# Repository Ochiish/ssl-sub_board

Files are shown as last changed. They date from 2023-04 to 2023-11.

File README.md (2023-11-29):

# SubBoard for SSL
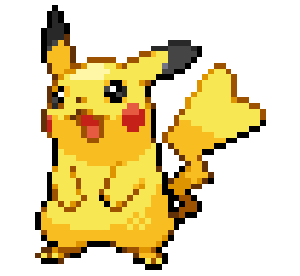
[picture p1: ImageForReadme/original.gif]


## Overview

This is a sub-board installed in the SSL robot.
The boost circuit, neopixel, phototransistor, etc. are controlled by stm32, and CAN communication is performed with the main board.

## Requirement

- KiCad 7.0.5

## Usage

Good luck...

## Features

This is a sub-board installed in an SSL robot. The board is equipped with various components such as a boost circuit, NeoPixels, phototransistors, etc., all controlled by an STM32 microcontroller. 

- This microcontroller offers advanced programming and processing capabilities, efficiently managing the robot's diverse functions.

- The boost circuit optimizes power supply, ensuring each component on the board operates at the correct voltage. It elevates the low voltage from the battery, distributing power as needed.

- NeoPixels are individually controllable LEDs used for visual feedback and status indication on the robot. These LEDs can be customized in color and brightness through programming, intuitively conveying the robot's status to the operator.

- Phototransistors detect light intensity and convert this information into digital signals. This is a crucial sensor for environmental awareness and obstacle detection in the robot.

- Furthermore, this robot is equipped with a thermistor for measuring the temperature of the solenoid coil. The thermistor plays a vital role in monitoring the heat generated by the solenoid, preventing overheating and enhancing the robot's safety and equipment lifespan.

- Additionally, the sub-board incorporates protective circuits around the power supply, safeguarding it against overvoltage and short circuits. 

- These circuits are essential for maintaining power stability while minimizing electrical risks.

- The sub-board communicates with the main board using the CAN communication protocol. CAN communication is known for its high reliability and error detection capabilities, ensuring secure data exchange between different parts of the robot. This allows for smooth overall operation and the ability to perform more complex tasks.

In this way, the sub-board supports crucial functions of the SSL robot, drawing out the robot's maximum performance through advanced technology and meticulous design.

<p align="center">
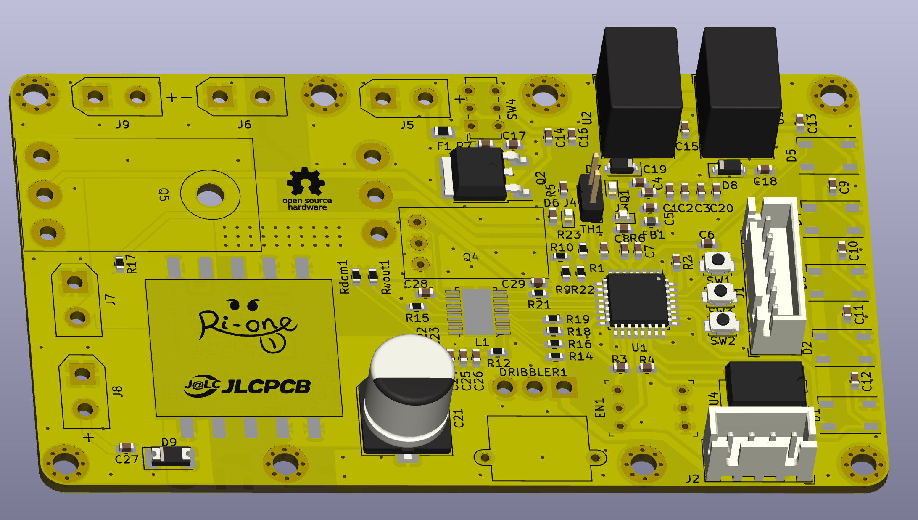
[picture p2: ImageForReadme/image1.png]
  

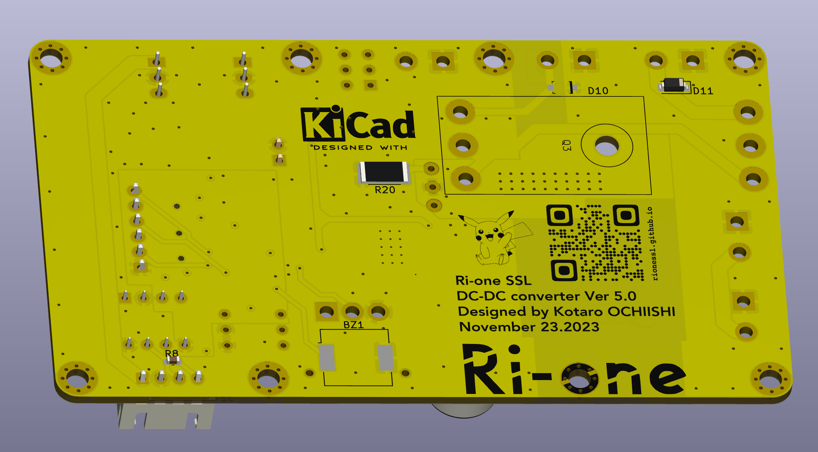
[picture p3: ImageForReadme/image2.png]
  
</p>

## Reference

https://www.analog.com/media/jp/technical-documentation/data-sheets/j3751fc.pdf

## Author

[@Allsatako](http://twitter.com/Allsatako)

mail to: rionesslq@gmail.com

## Licence

There is no license as this is open source hardware.

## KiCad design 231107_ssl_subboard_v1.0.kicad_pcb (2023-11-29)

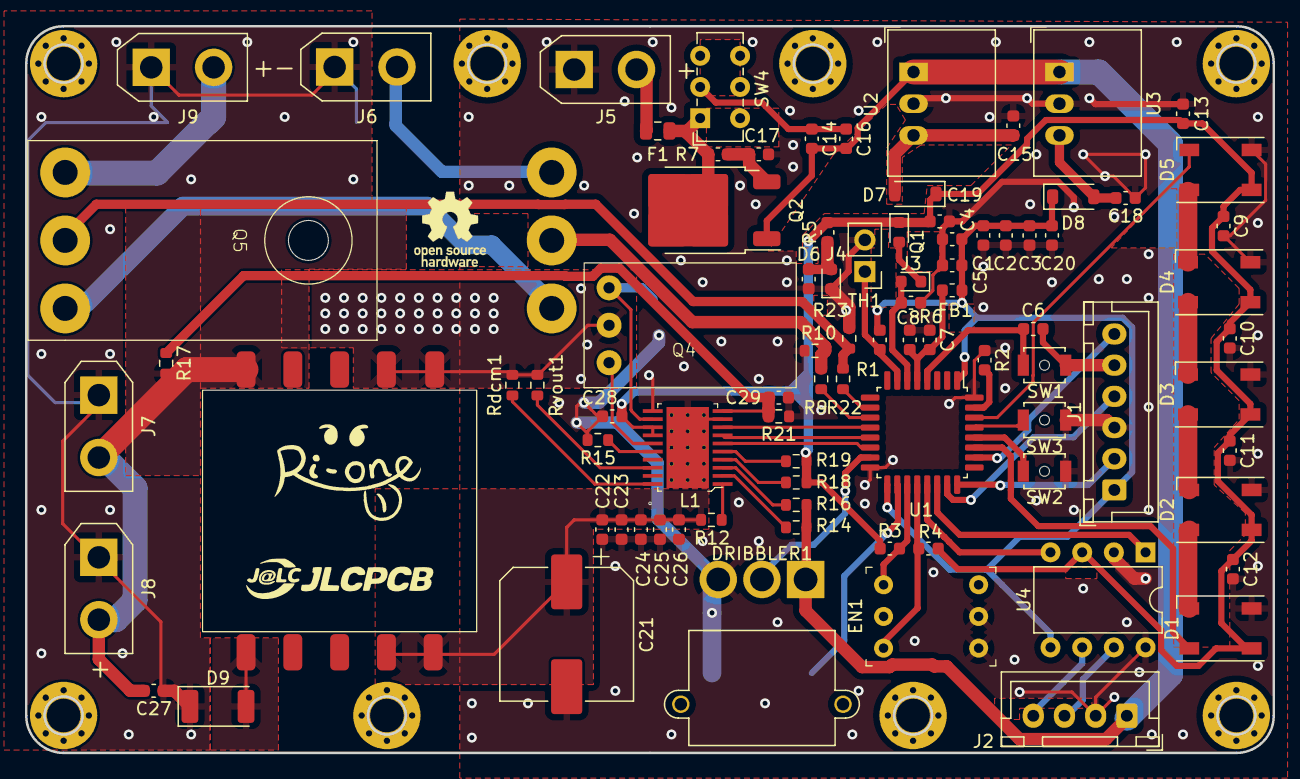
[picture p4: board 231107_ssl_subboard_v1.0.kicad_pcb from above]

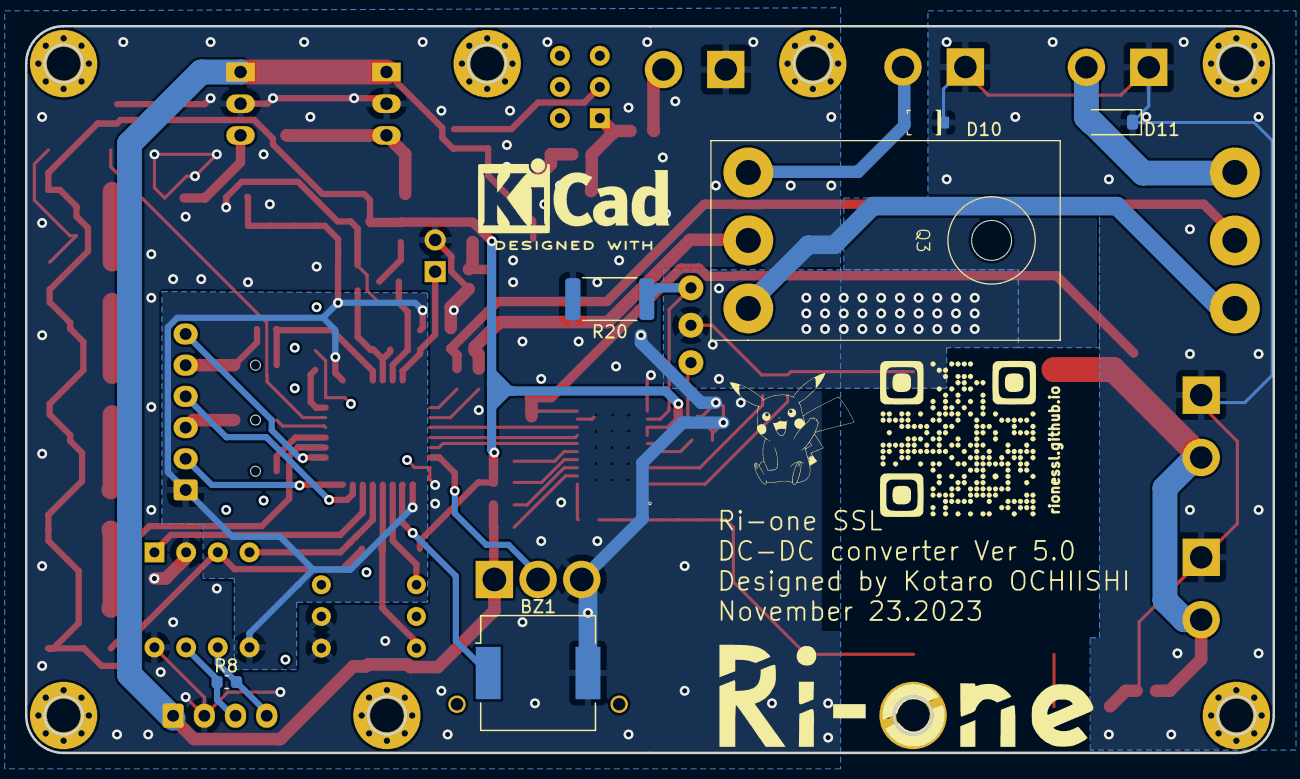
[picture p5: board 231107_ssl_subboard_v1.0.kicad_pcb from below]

Board: 2 copper layers, 100.0 x 58.2 mm, 93 parts (6 on the bottom side), 62 nets.

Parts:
BZ1: Buzzer; Buzzer_CUI_CPT-9019S-SMT
C1, C2, C3, C4, C5, C6, C7, C8, C9, C10, C11, C12, C13, C14, C16, C17, C19, C20: 0.1uF; C_0603_1608Metric
C15, C18, C22, C23, C24, C25, C26: 2.2u; C_0603_1608Metric
C21: 680u; CP_Elec_10x10.5
C27: 0.47u; C_0603_1608Metric
C28, C29: 10n; C_0603_1608Metric
D1, D2, D3, D4, D5: ws2812b; LED_Cree-PLCC4_5x5mm_CW
D6: LED; C_0603_1608Metric
D7, D8: SS2040FL; D_SOD-123
D9: 1.5KExxA; D_2010_5025Metric
D10: 1.5KExxA; SOD-123
D11: 1.5KExxA; D_SOD-123
DRIBBLER1: MR30PW-M; AMASS_MR30PW-M_1x03_P3.50mm_Horizontal
EN1: RotaryEncoder_Switch; SOCKET_DIP-6_7.62mm_Conn
F1: Fuse; Fuse_0805_2012Metric
FB1: FerriteBead_Small; L_0603_1608Metric
J1: pc to stm32; JST_XH_B6B-XH-A_1x06_P2.50mm_Vertical
J2: main to sub; JST_XH_B4B-XH-A_1x04_P2.50mm_Vertical
J3: PHOTOCOUPLER; LED_0603_1608Metric
J4: LED; LED_0603_1608Metric
J5: lipo_3cell; AMASS_XT30UPB-M_1x02_P5.0mm_Vertical
J6: s1; AMASS_XT30UPB-F_1x02_P5.0mm_Vertical
J7: c1; AMASS_XT30UPB-F_1x02_P5.0mm_Vertical
J8: c2; AMASS_XT30UPB-F_1x02_P5.0mm_Vertical
J9: s2; AMASS_XT30UPB-F_1x02_P5.0mm_Vertical
L1: TSSOP-20-1EP_W4.4mm
Q1: Q_Photo_NPN; LED_0603_1608Metric
Q2: PMOS; TO-252-2
Q3, Q5: NMOS; IRFP150NPbF
Q4: Q_NMOS_DGS; tk20a60u
R1, R3, R4: 5k; C_0603_1608Metric
R2, R7: 10k; C_0603_1608Metric
R5: 470; C_0603_1608Metric
R6: 20k; C_0603_1608Metric
R8: 120; C_0603_1608Metric
R9, R22: 100; R_0603_1608Metric
R10, R23: 1k; R_0603_1608Metric
R12: 40.2k; R_0603_1608Metric
R14, R18: 69.8k; R_0603_1608Metric
R15: 1.65; R_0603_1608Metric
R16, R19: 475k; R_0603_1608Metric
R17: 124; R_0603_1608Metric
R20: 6m; R_2512_6332Metric
R21: 0.768k; R_0603_1608Metric
Rdcm1: 18.2k; R_0603_1608Metric
Rvout1: 40.2k; R_0603_1608Metric
SW1, SW2, SW3: SW_Push; SW_SPST_B3U-1000P-B
SW4: SW_SPST; SW_E-Switch_EG1271_SPDT
TH1: Thermistor; PinHeader_1x02_P2.54mm_Vertical
U1: STM32F303K8Tx; LQFP-32_7x7mm_P0.8mm
U2: M78AR05-1; Converter_DCDC_RECOM_R-78E-0.5_THT
U3: M78AR033-1; Converter_DCDC_RECOM_R-78E-0.5_THT
U4: MCP2562-E-P; DIP-8_W7.62mm
U5: 32052

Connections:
+3V3: C1.2, C2.2, C3.2, C4.2, C5.2, C20.2, D8.1 (K), FB1.1, J1.1, R1.2, U1.1 (VDD), U1.17 (VDD), U4.5 (Vio)
+5V: C9.1, C10.1, C11.1, C12.1, C13.1, C19.2, C28.1, D1.3 (VDD), D2.3 (VDD), D3.3 (VDD), D4.3 (VDD), D5.3 (VDD), D7.1 (K), L1.13 (VCC), L1.14 (LVGATE), Q1.1 (C), R3.1, R4.1, R5.2, R18.1, R19.1, U4.3 (VDD)
+15V: C14.2, C16.2, DRIBBLER1.1, J2.1, Q2.1 (D), R14.1, R16.1, U2.1 (IN), U3.1 (IN)
+BATT: F1.1, J5.2
CANH: J2.3, R8.2, U4.7 (CANH)
CANL: J2.4, R8.1, U4.6 (CANL)
CANRX: U1.21 (PA11), U4.4 (RXD)
CANTX: U1.22 (PA12), U4.1 (TXD)
CHARGE: L1.8 (CHARGE), U1.12 (PA6)
Cvtrans: C21.1, C22.1, C23.1, C24.1, C25.1, C26.1, R12.1, U5.4 (4IN), U5.5 (5IN)
DCDC_OUT: C27.1, D9.1 (A1), D10.1 (A1), D11.1 (A1), J6.1, J7.1, J8.1, J9.1
DIN: D1.4 (DIN), U1.27 (PB4)
DONE: L1.7 (DONE), U1.13 (PA7)
DOUT: D5.1 (DOUT), U1.30 (PB7)
DR_PWM: DRIBBLER1.2, U1.15 (PB1)
DR_SW: SW3.2, U1.29 (PB6)
Drain: Q4.1 (D), Rdcm1.2, Rvout1.2, U5.6 (6IN), U5.7 (7IN)
ENCODER_A: EN1.1 (A), R3.2, U1.19 (PA9)
ENCODER_B: EN1.3 (B), R4.2, U1.20 (PA10)
FAULT: L1.6 (FAULT), U1.14 (PB0)
GND: BZ1.2 (+), C1.1, C2.1, C3.1, C4.1, C5.1, C7.1, C8.1, C9.2, C10.2, C11.2, C12.2, C13.2, C15.1, C17.1, C18.1, C19.1, C20.1, C21.2, C22.2, C23.2, C24.2, C25.2, C26.2, C28.2, C29.2, D1.2 (GND), D2.2 (GND), D3.2 (GND), D4.2 (GND), D5.2 (GND), D6.1 (K), DRIBBLER1.3, EN1.4 (S1), EN1.5 (S2), J1.3, J2.2, J4.1, J5.1, L1.9 (CLAMP), L1.11 (CSN), L1.21 (GND), Q3.3 (S), Q5.3 (S), R2.1, R6.2, R10.1, R15.2, R20.2, R21.1, R23.1, SW2.1, SW3.1, TH1.2, U1.16 (VSS), U1.32 (VSS), U2.2 (GND), U3.2 (GND), U4.2 (VSS), U4.8 (STBY)
KICK_SW: SW2.2, U1.28 (PB5)
NRST: C6.1, J1.5, SW1.1
unnamed: BZ1.1 (-), U1.18 (PA8)
unnamed: D1.1 (DOUT), D2.4 (DIN)
unnamed: D2.1 (DOUT), D3.4 (DIN)
unnamed: D3.1 (DOUT), D4.4 (DIN)
unnamed: D4.1 (DOUT), D5.4 (DIN)
unnamed: D6.2 (A), J4.2, R5.1
unnamed: C15.2, D7.2 (A), U2.3 (OUT)
unnamed: C18.2, D8.2 (A), U3.3 (OUT)
unnamed: D10.2 (A2), J6.2, Q3.1 (D)
unnamed: D11.2 (A2), J9.2, Q5.1 (D)
unnamed: J3.1, Q1.2 (E)
unnamed: L1.12 (CSP), Q4.3 (S), R20.1
unnamed: C29.1, L1.10 (FB), R17.1, R21.2
unnamed: L1.15 (HVGATE), Q4.2 (G)
unnamed: L1.3 (OVLO1), R16.2
unnamed: L1.5 (OVLO2), R19.2
unnamed: L1.16 (RBG), R15.1
unnamed: L1.20 (RDCM), Rdcm1.1
unnamed: L1.18 (RVOUT), Rvout1.1
unnamed: L1.1 (RVTRANS), R12.2
unnamed: L1.2 (UVLO1), R14.2
unnamed: L1.4 (UVLO2), R18.2
unnamed: F1.2, Q2.2 (G), R7.2, SW4.1 (A)
unnamed: C17.2, Q2.3 (S), R7.1
unnamed: Q3.2 (G), R9.2, R10.2
unnamed: Q5.2 (G), R22.2, R23.2
unnamed: C14.1, C16.1, SW4.2 (B)
unnamed: R2.2, U1.31 (BOOT0)
unnamed: C6.2, SW1.2, U1.4 (NRST)
unnamed: R1.1, TH1.1, U1.7 (PA1)
unnamed: C7.2, C8.2, FB1.2, U1.5 (VDDA)
STRAIGHT: R9.1, U1.11 (PA5)
SYS-SWCLK: J1.2, U1.24 (PA14)
SYS-SWDIO: J1.4, U1.23 (PA13)
SYS-SWO: J1.6, U1.26 (PB3)
TR_SIG: J3.2, R6.1, U1.6 (PA0)
Vout: D9.2 (A2), U5.1 (1OUT)
tip: R22.1, U1.10 (PA4)
trans2: C27.2, J7.2, J8.2, R17.2, U5.10 (10OUT)

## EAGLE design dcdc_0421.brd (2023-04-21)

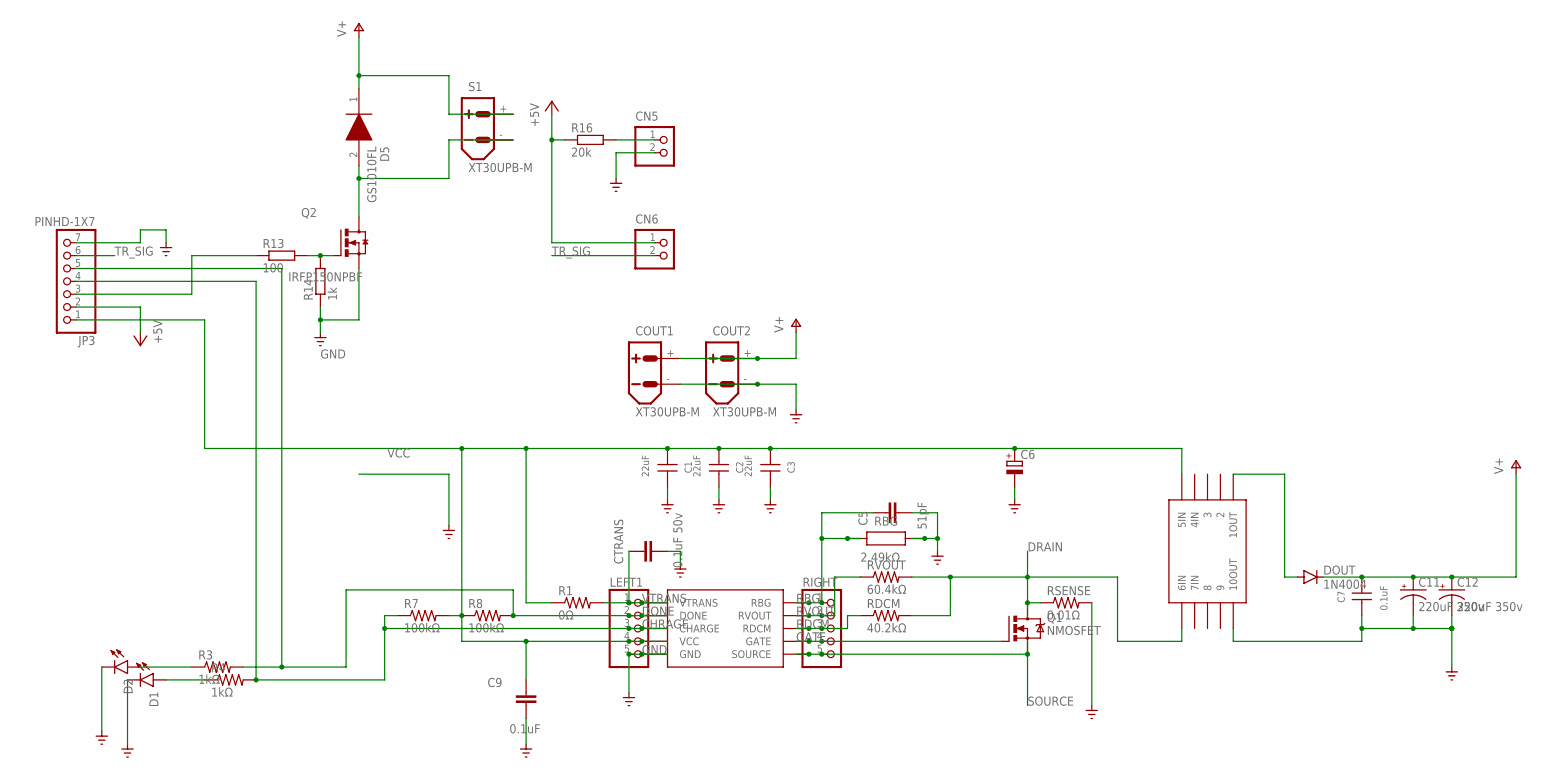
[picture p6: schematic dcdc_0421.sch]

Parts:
C1, C2, C3: 22uF; WCAP-CSGP_1210_H0.95
C5: 51pF; CAP_0603
C6: CPOL-EUTT2D6; TT2D6
C7: 0.1uF; WCAP-CSGP_1812_H1.25
C9: 0.1uF; CAP_0603
C11, C12: 220uF 350v; E7,5-18
CN5, CN6: S2B-XH-A
COUT1, COUT2: XT30UPB-M
CTRANS: 0.1uF 50v; CAP_1206
D1, D2: LED_RADIALWHITE; LEDRD254W60D565H860B_W
D5: GS1010FL; SODFL3618X110N
DOUT: 1N4004; DO41-10
JP3: PINHD-1X7; 1X07
LEFT1: PINHD-1X5; 1X05
Q1: NMOSFET; TO220BV
Q2: IRFP150NPBF; TO-247AC
R1: 0Ω; M2012
R3, R4: 1kΩ; RES_0402
R7, R8: 100kΩ; R1210
R13: 100; R0603
R14: 1k; R0603
R16: 20k; R0603
RBG: 2.49kΩ; WRIS_PSMC_2512_6.3X3.1X0.51X1.1(LXWXHXPW)
RDCM: 40.2kΩ; RES_0805
RIGHT: PINHD-1X5; 1X05
RSENSE: 0.01Ω; RES_1206
RVOUT: 60.4kΩ; RES_0805
S1: XT30UPB-M
U$1: LT3750_2
U$2: 32052

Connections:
2: D5.2 (A), Q2.D, S1.-
+5V: CN6.1, JP3.2, R16.1
CHRAGE: JP3.4, LEFT1.3, R4.2, R7.1, U$1.CHARGE
DONE: JP3.5, LEFT1.2, R3.2, R8.2, U$1.DONE
DRAIN: Q1.D, RDCM.2, RSENSE.1, RVOUT.2, U$2.6IN
GATE: Q1.G, RIGHT.4, U$1.GATE
GND: C1.2, C2.2, C3.2, C5.2, C6.-, C7.1, C9.2, C11.-, C12.-, CN5.2, COUT1.-, COUT2.-, CTRANS.2, D1.C, D2.C, JP3.7, LEFT1.5, Q2.S, R14.1, RBG.2, RSENSE.2, U$1.GND, U$2.10OUT
unnamed: JP3.3, R13.1
unnamed: DOUT.A, U$2.1OUT
unnamed: D1.A, R4.1
unnamed: D2.A, R3.1
unnamed: Q2.G, R13.2, R14.2
unnamed: CN5.1, R16.2
RBG: C5.1, RBG.1, RIGHT.1, U$1.RBG
RDCM: RDCM.1, RIGHT.3, U$1.RDCM
RVOUT: RIGHT.2, RVOUT.1, U$1.RVOUT
SOURCE: Q1.S, RIGHT.5, U$1.SOURCE
TR_SIG: CN6.2, JP3.6
V+: C7.2, C11.+, C12.+, COUT1.+, COUT2.+, D5.1 (K), DOUT.C, S1.+
VCC: C1.1, C2.1, C3.1, C6.+, C9.1, JP3.1, LEFT1.4, R1.1, R7.2, R8.1, U$1.VCC, U$2.5IN
VTRANS: CTRANS.1, LEFT1.1, R1.2, U$1.VTRANS

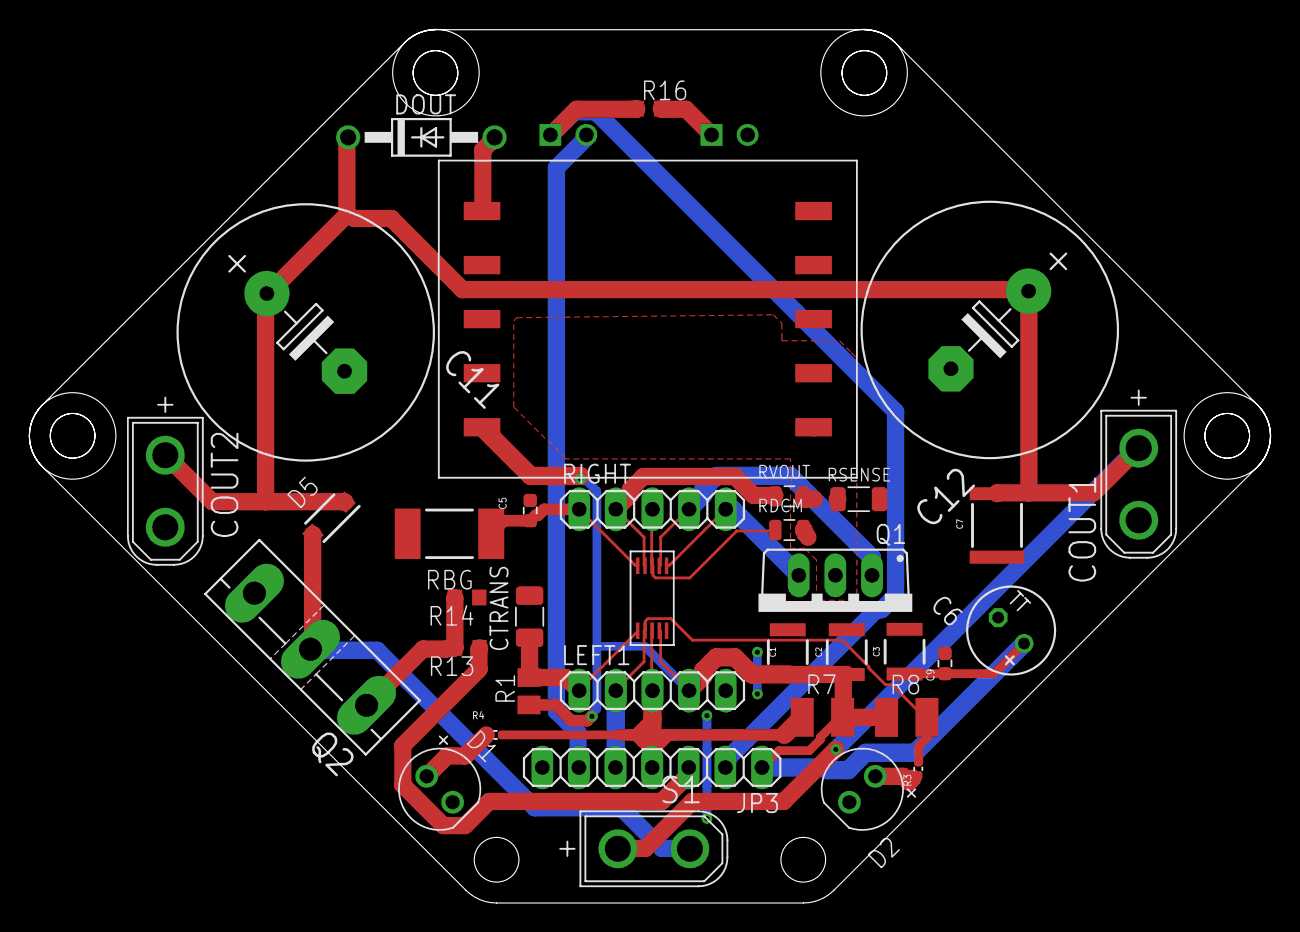
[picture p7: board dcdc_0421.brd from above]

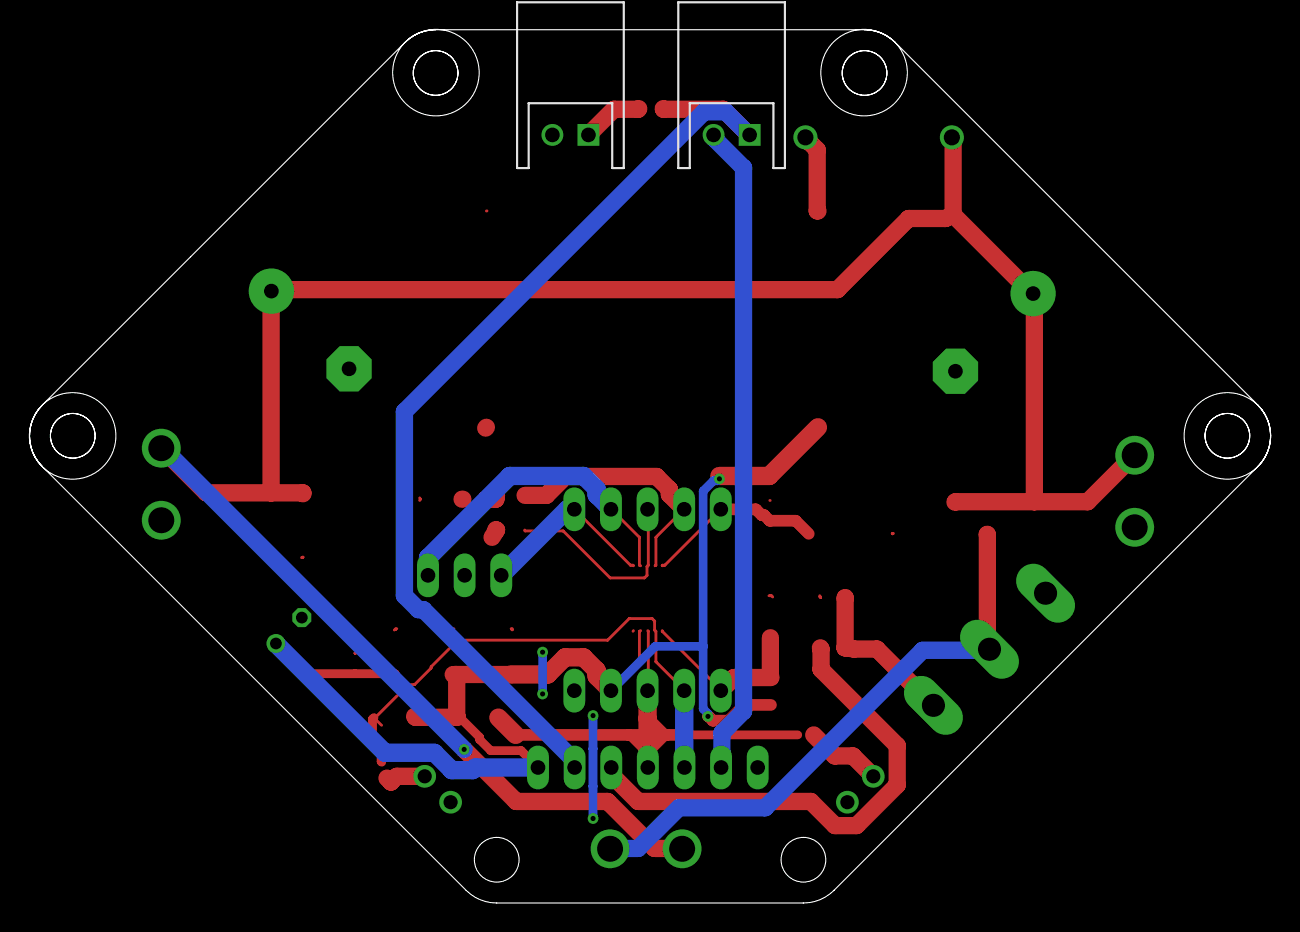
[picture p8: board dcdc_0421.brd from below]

Board: 2 copper layers, 86.1 x 60.6 mm, 38 parts (2 on the bottom side), 21 nets.

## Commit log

2023-02-23 second commit
    [dcdc 1.1 0223.brd, dcdc 1.1 0223.sch]
2023-02-24 third commit
    [dcdc 1.1 0223.brd, dcdc 1.2 0224.brd, dcdc 1.2 0224.sch]
2023-05-24 Add files via upload
    designed with kicad
    [dcdc0517.kicad_pcb, dcdc0517.kicad_sch]
2023-06-27 last circuit
    [dcdc0603.kicad_sch]
2023-11-29 add .gitignore
    [231107_ssl_subboard_v1.0.kicad_pcb, dcdc2.0_0928.kicad_pcb, dcdc2.0_0928.kicad_sch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]

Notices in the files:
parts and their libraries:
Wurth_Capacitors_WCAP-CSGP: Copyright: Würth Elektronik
